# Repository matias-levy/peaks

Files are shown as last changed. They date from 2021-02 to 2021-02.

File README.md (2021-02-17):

# $peaks, a fully-functional low-cost reversion of [Mutable instrument's Peaks](https://mutable-instruments.net/modules/peaks/)

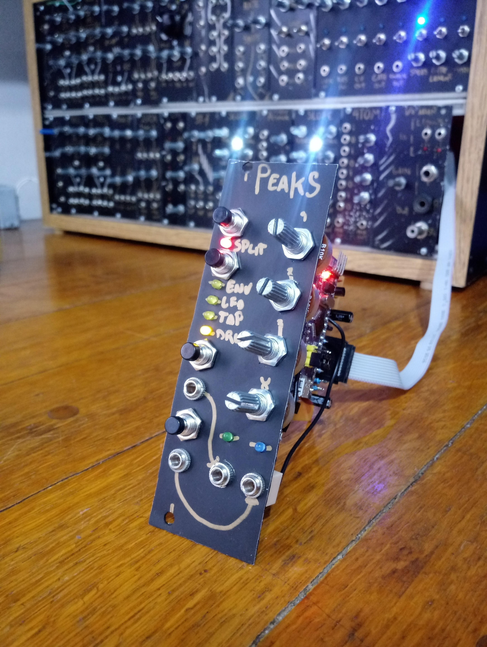
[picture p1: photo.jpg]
Photo of the finished build


## Motivation
Where I am from it is sometimes very difficult to source components for digital Eurorack modules, but I had my eyes on Peaks for a long time and I wanted to do something cheap with the same functionality. The basic premise was to use a bluepill (stm32f103c8t6 development board) and omit the DAC IC, relying on a technic called dual PWM as it is described in [openmusiclabs blog](http://www.openmusiclabs.com/learning/digital/pwm-dac/dual-pwm-circuits/index.html) and used, for example, in the popular [Mozzi Library](https://github.com/sensorium/Mozzi) for Arduino.

## Description
The project uses a single sided home-etched PCB with a couple of jumper wires, the potentiometers are regular 16mm ones mounted at the side, also helping with the mechanical stability of the build. <br>
You will need a bluepill capable of 128kb of flash, I bought mine advertised as only having 64kb, but it ended up not being the case, so it's worth the try

## Firmwares
There's the option to flash one of two firmwares that where ported. The original Mutable Instruments one is in the firmware/peaks directory. The [Mutated Mutables Dead Man's Catch](https://github.com/timchurches/Mutated-Mutables/tree/master/peaks) is in the firmware/peaks2. The later adds a lot of functionality to the module, although the UI becomes a bit confusing. <br>
Compiled binaries and HEX files are provided for both under firmware/build.

## Changes
* Added a driver for the PWM DAC running at **14 bit depth, 48Khz sampling rate.** (File in firmware/peaks/drivers/pwm_dac.h)
* Activated the clock for the TIM4 in firmware/peaks/drivers/system.cc
* **Bypassed the bootloader:** This was done as to simplify the code, it does not interfere with the calibration functionality of the module.
* Redesigned the output portion of the hardware to accommodate to the PWM levels. 

## Flashing and development
To make it easier I have left binaries and .HEX files in firmware/build, this can be flashed directly to the bluepill using [STM32CubeProgrammer](https://www.st.com/en/development-tools/stm32cubeprog.html). <br>
Another option is to install the [mutable-dev-environment](https://github.com/pichenettes/mutable-dev-environment) and replace the peaks folder with the one inside /firmware, then executing

    make -f peaks/makefile upload_serial

We use this command because the bootloader is bypassed.

## Thanks
I want to thank Emilie Gillet for open-sourcing her work which is a constant inspiration for many musicians and makers, and encourage everyone interested in this project to checkout the [Mutable instrument's Forum](https://forum.mutable-instruments.net/) in which Emilie is a very active member.

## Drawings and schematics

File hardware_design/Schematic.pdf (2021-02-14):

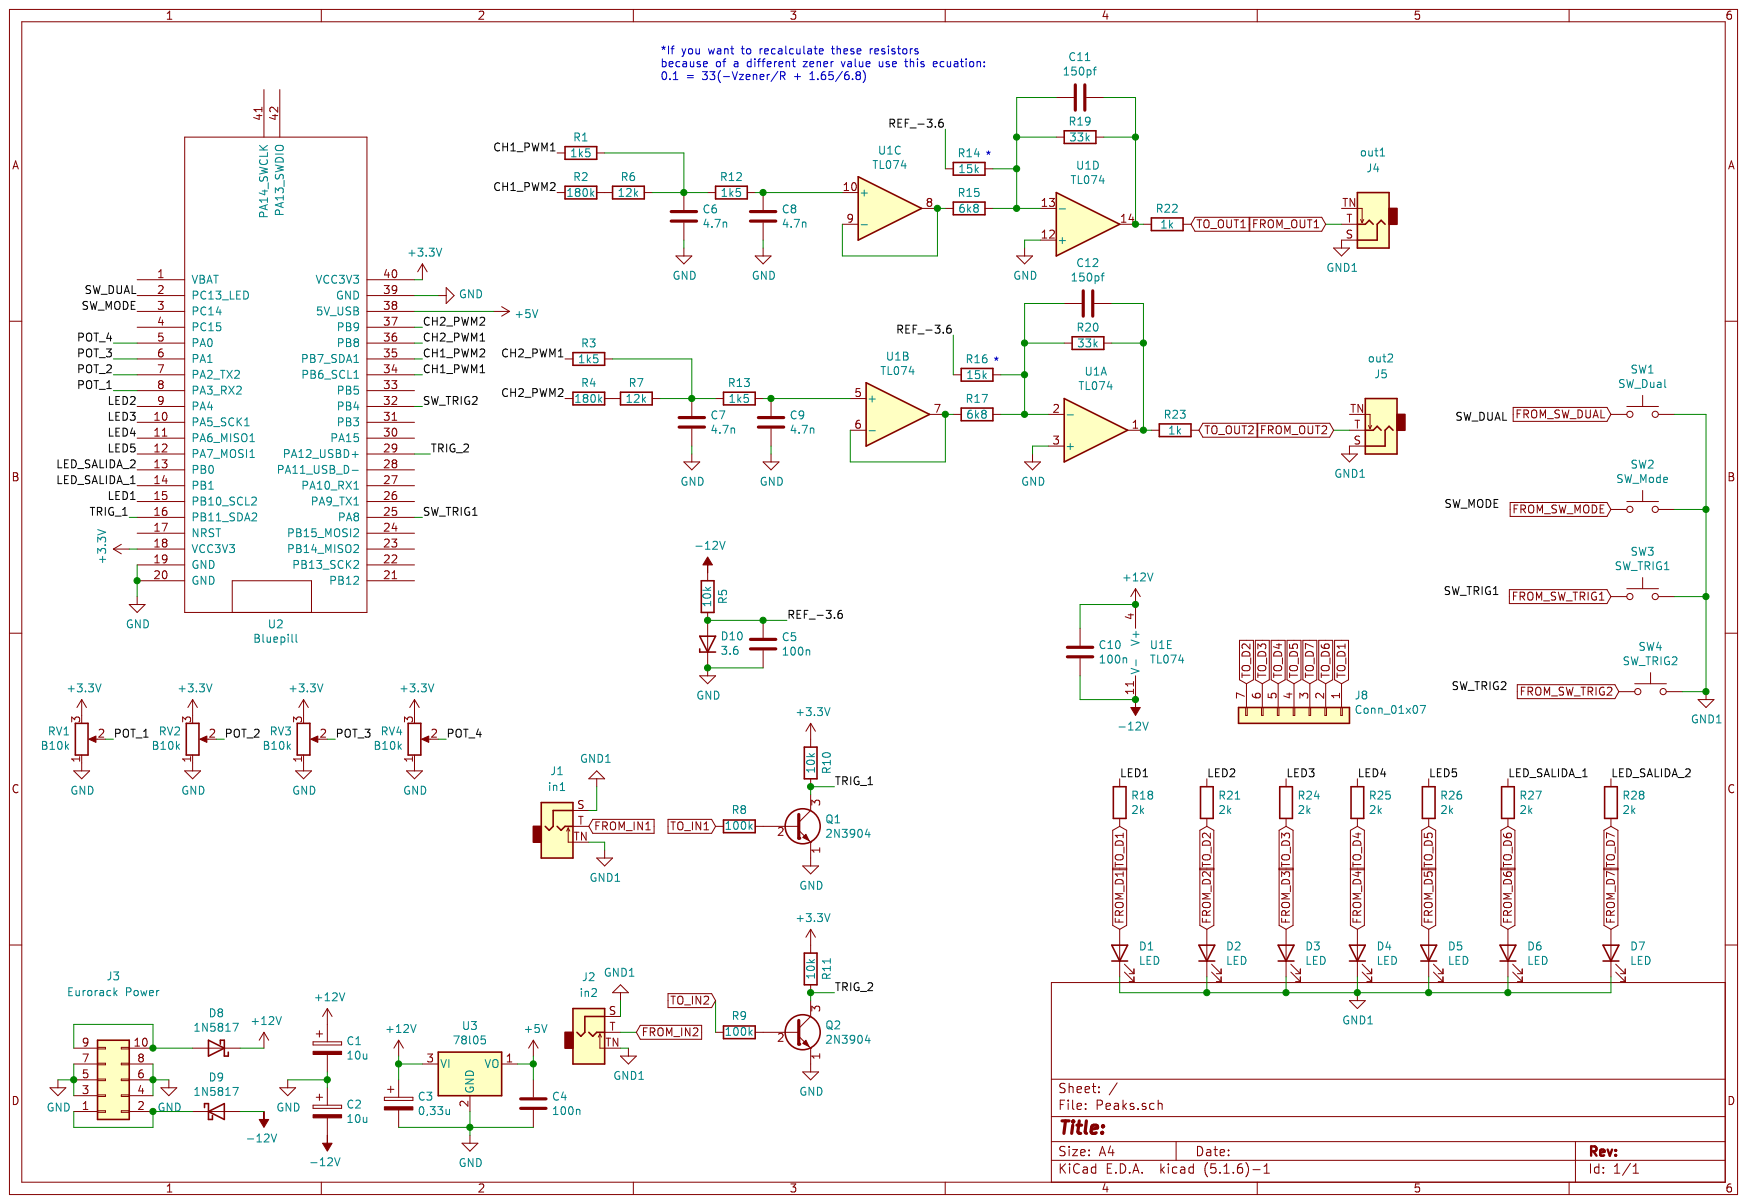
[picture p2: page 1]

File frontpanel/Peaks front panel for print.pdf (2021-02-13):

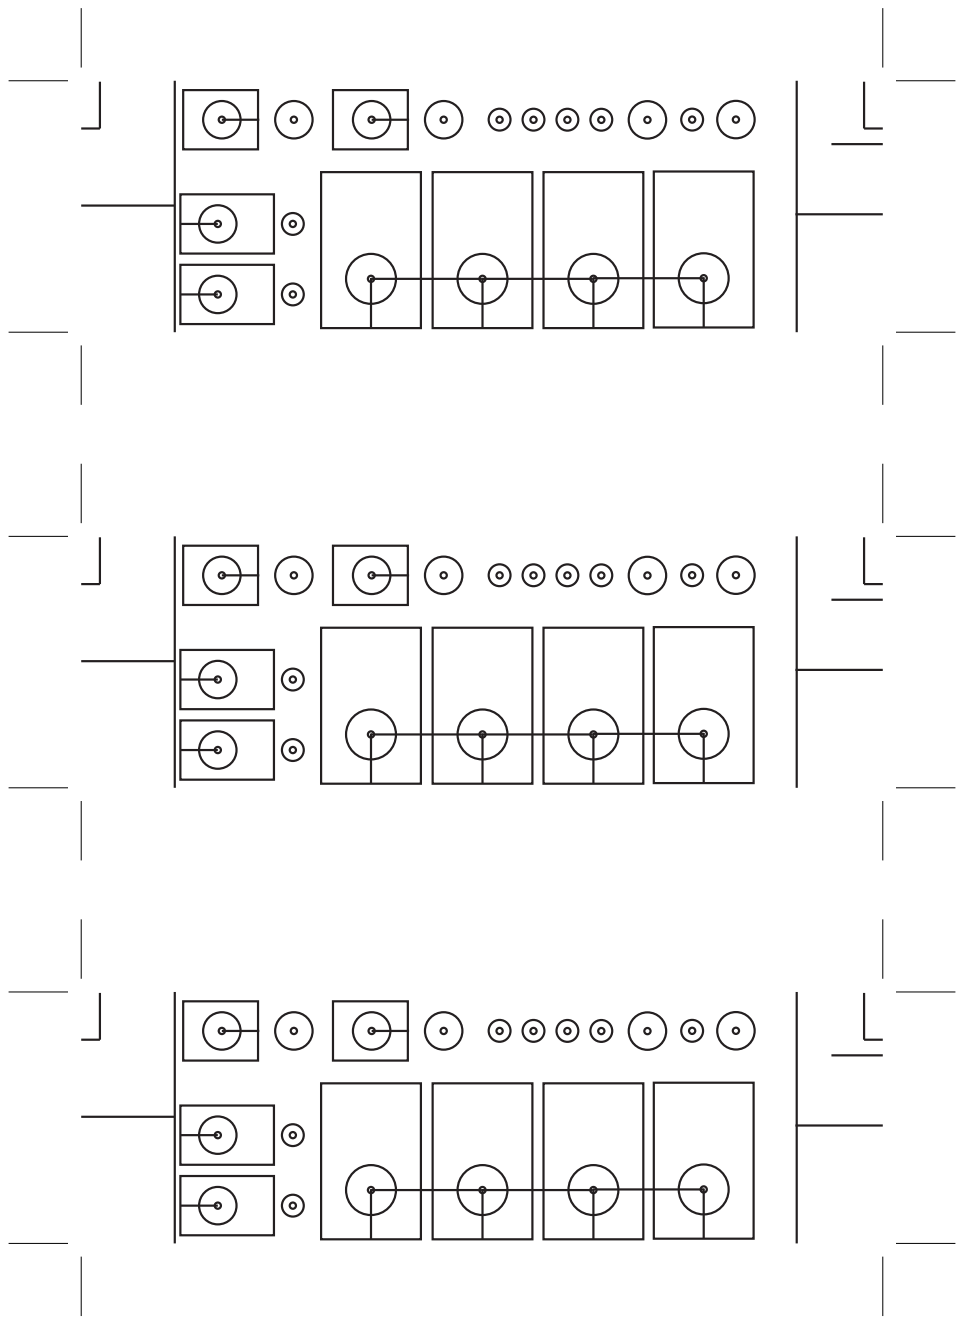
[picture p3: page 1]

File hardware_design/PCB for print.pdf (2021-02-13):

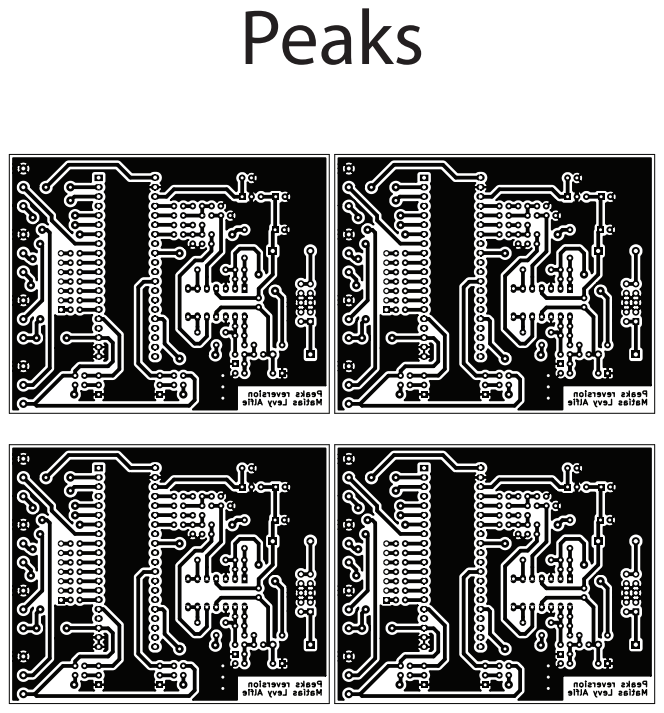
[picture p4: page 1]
Peaks

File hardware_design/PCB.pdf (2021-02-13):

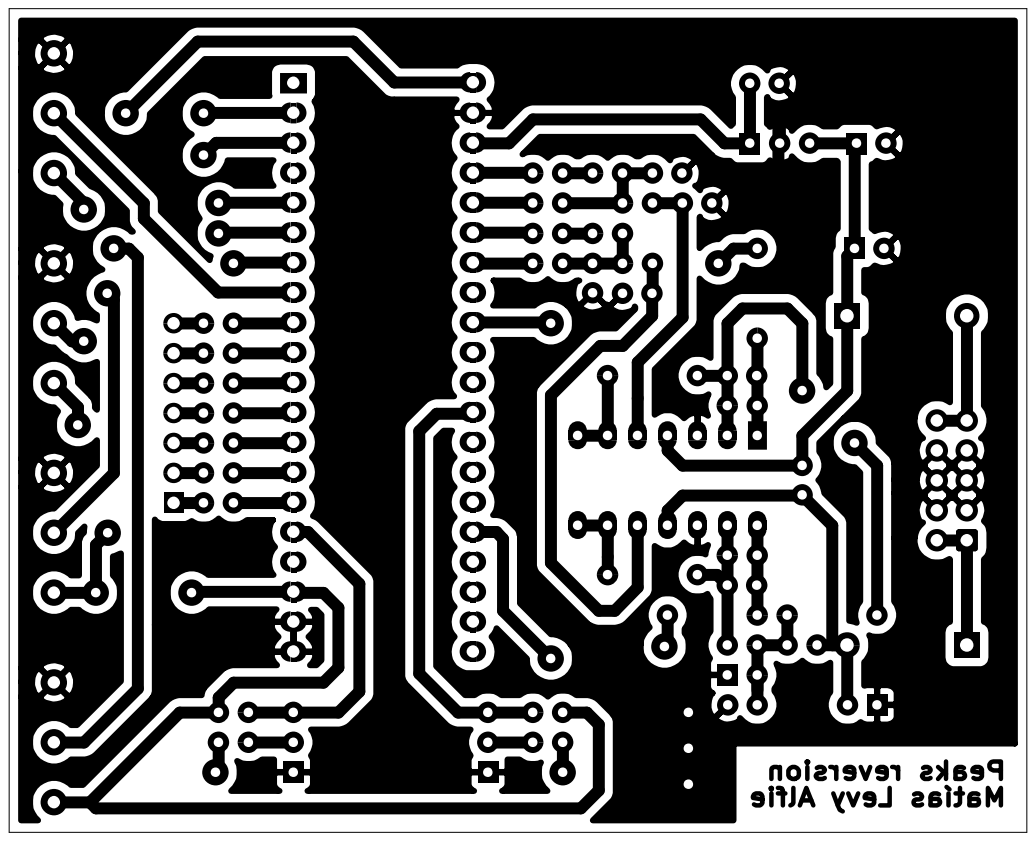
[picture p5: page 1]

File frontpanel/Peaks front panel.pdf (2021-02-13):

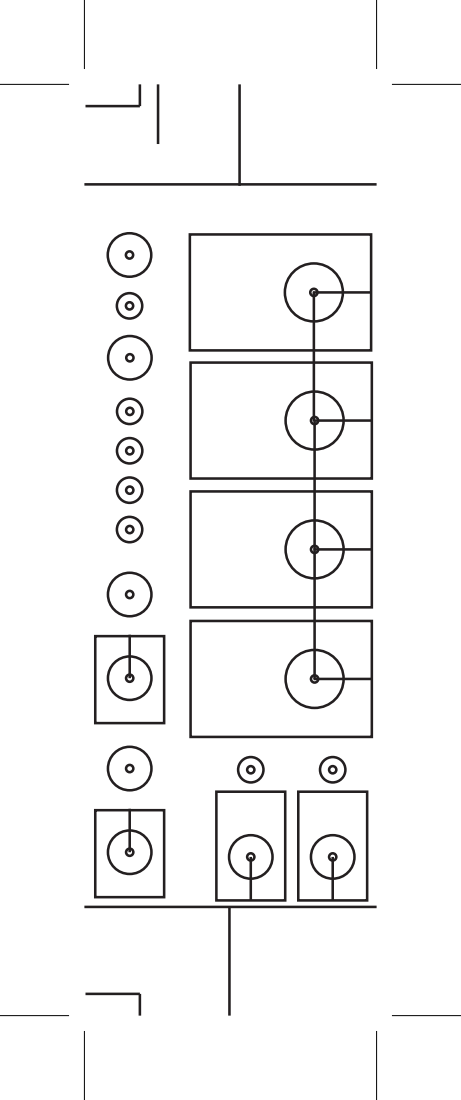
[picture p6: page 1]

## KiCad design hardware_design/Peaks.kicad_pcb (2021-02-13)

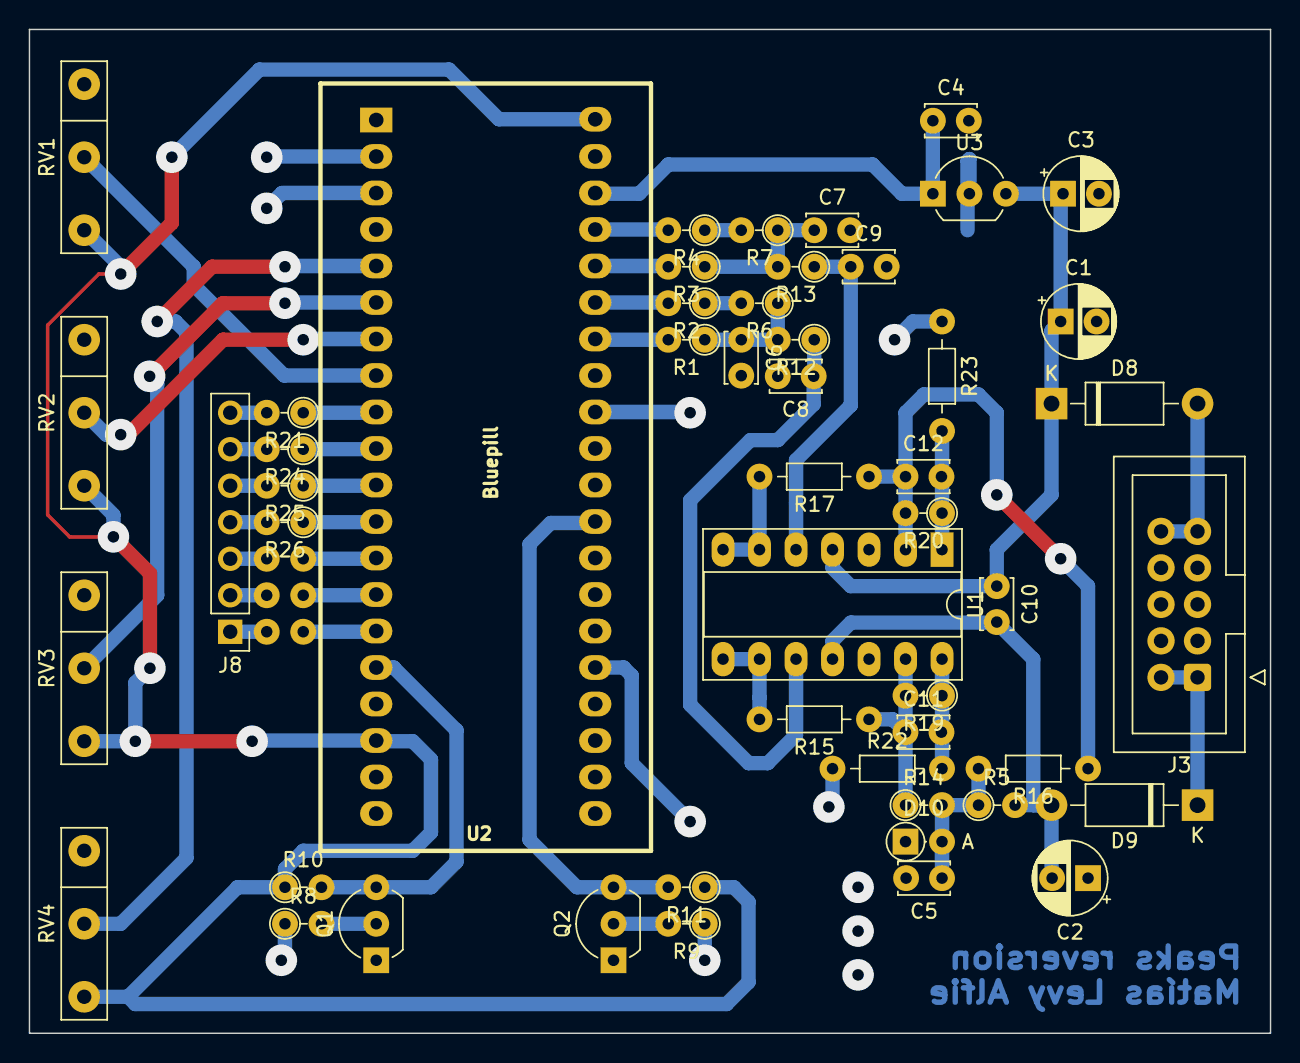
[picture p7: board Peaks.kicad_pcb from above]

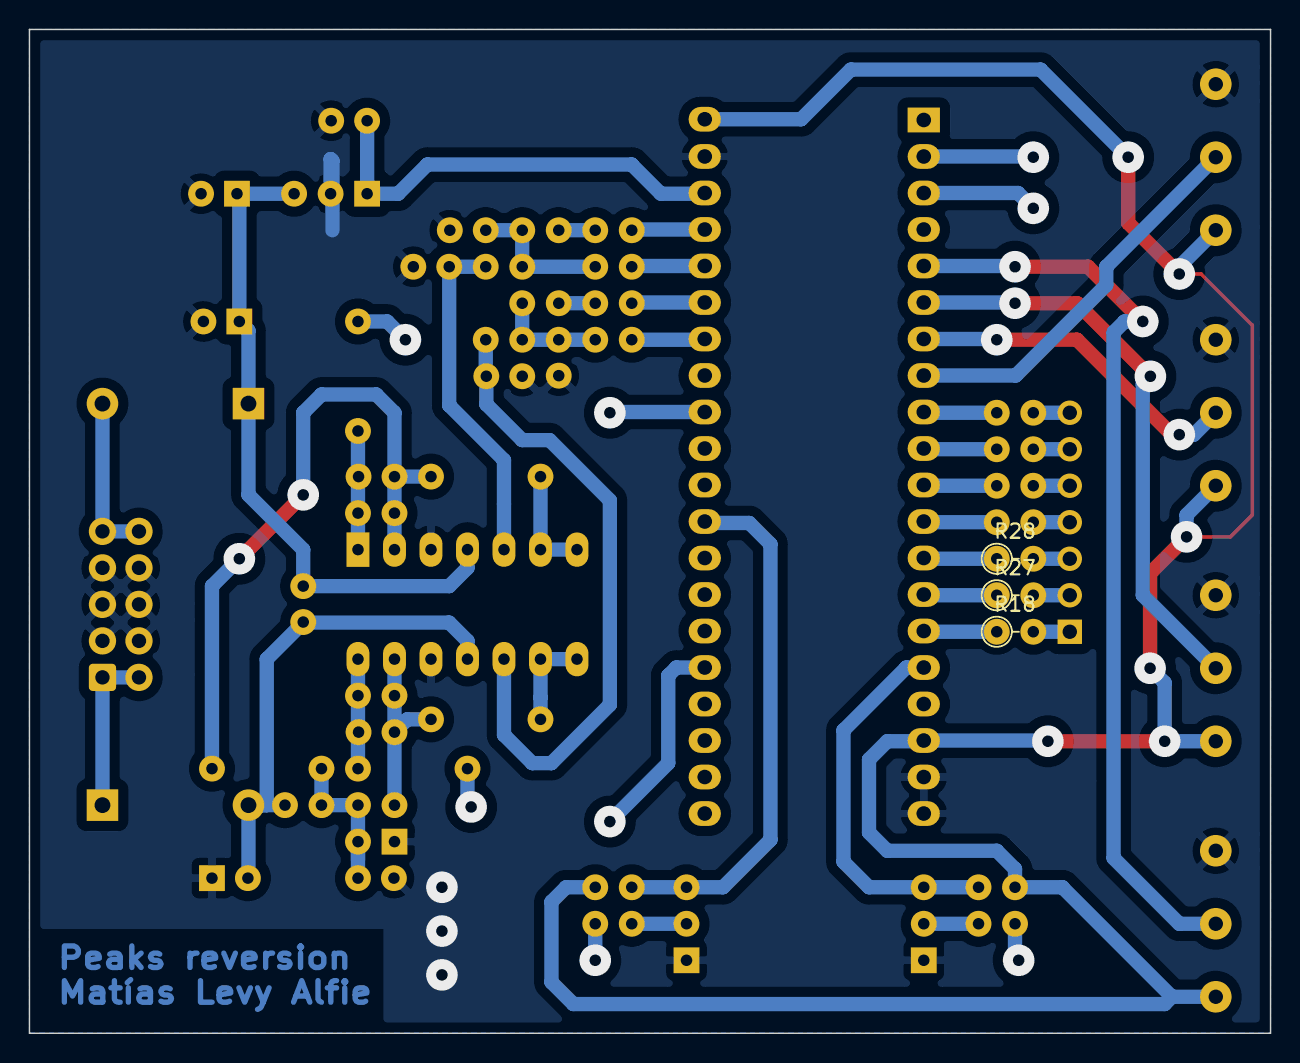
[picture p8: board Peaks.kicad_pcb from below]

Board: 2 copper layers, 86.4 x 69.8 mm, 54 parts (3 on the bottom side), 46 nets.

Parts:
C1, C2: 10u; CP_Radial_D5.0mm_P2.50mm_Large_Pads
C3: 0,33u; CP_Radial_D5.0mm_P2.50mm_Large_Pads
C4, C5, C10: 100n; C_Disc_D3.4mm_W2.1mm_P2.50mm_Large_Pads
C6, C7, C8, C9: 4.7n; C_Disc_D3.4mm_W2.1mm_P2.50mm_Large_Pads
C11, C12: 150pf; C_Disc_D3.4mm_W2.1mm_P2.50mm_Large_Pads
D8, D9: 1N5817; D_DO-41_SOD81_P10.16mm_Horizontal
D10: 3.6; D_DO-35_SOD27_P2.54mm_Vertical_AnodeUp_Large_Pads
J3: Eurorack Power; IDC-Header_2x05_P2.54mm_Vertical_Large_Pads
J8: Conn_01x07; PinHeader_1x07_P2.54mm_Vertical
Q1, Q2: 2N3904; TO-92_Inline_Wide_Large_Pads
R1, R3, R12, R13: 1k5; R_Axial_DIN0204_L3.6mm_D1.6mm_P2.54mm_Vertical_Large_Pads
R2, R4: 180k; R_Axial_DIN0204_L3.6mm_D1.6mm_P2.54mm_Vertical_Large_Pads
R5, R10, R11: 10k; R_Axial_DIN0204_L3.6mm_D1.6mm_P2.54mm_Vertical_Large_Pads
R6, R7: 12k; R_Axial_DIN0204_L3.6mm_D1.6mm_P2.54mm_Vertical_Large_Pads
R8, R9: 100k; R_Axial_DIN0204_L3.6mm_D1.6mm_P2.54mm_Vertical_Large_Pads
R14: 15k; R_Axial_DIN0204_L3.6mm_D1.6mm_P2.54mm_Vertical_Large_Pads
R15, R17: 6k8; R_Axial_DIN0204_L3.6mm_D1.6mm_P7.62mm_Horizontal_Large_Pads
R16: 15k; R_Axial_DIN0204_L3.6mm_D1.6mm_P7.62mm_Horizontal_Large_Pads
R18, R21, R24, R25, R26, R27, R28: 2k; R_Axial_DIN0204_L3.6mm_D1.6mm_P2.54mm_Vertical_Large_Pads
R19, R20: 33k; R_Axial_DIN0204_L3.6mm_D1.6mm_P2.54mm_Vertical_Large_Pads
R22, R23: 1k; R_Axial_DIN0204_L3.6mm_D1.6mm_P7.62mm_Horizontal_Large_Pads
RV1, RV2, RV3, RV4: B10k; Potenciometro
U1: TL074; DIP-14_W7.62mm_Socket_LongPads
U2: Bluepill; BluePill_STM32F103C
U3: 78l05; TO-92_Inline_Wide_Large_Pads

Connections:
+3V3: R10.1, R11.1, RV1.3, RV2.3, RV3.3, RV4.3, U2.18, U2.40
+5V: C4.1, U2.38, U3.1
+12V: C1.1, C3.1, C10.1, D8.1, U1.4, U3.3
-12V: C2.2, C10.2, D9.2, R5.2, U1.11
/CH1_PWM1: R1.2, U2.34
/CH1_PWM2: R2.2, U2.35
/CH2_PWM1: R3.2, U2.36
/CH2_PWM2: R4.2, U2.37
/LED1: R18.1, U2.15
/LED2: R21.1, U2.9
/LED3: R24.1, U2.10
/LED4: R25.1, U2.11
/LED5: R26.1, U2.12
/LED_SALIDA_1: R27.1, U2.14
/LED_SALIDA_2: R28.1, U2.13
/POT_1: RV1.2, U2.8
/POT_2: RV2.2, U2.7
/POT_3: RV3.2, U2.6
/POT_4: RV4.2, U2.5
/REF_-3.6: C5.1, D10.2, R5.1, R14.2, R16.2
/TRIG_1: Q1.3, R10.2, U2.16
/TRIG_2: Q2.3, R11.2, U2.29
GND: C1.2, C2.1, C3.2, C4.2, C5.2, C6.2, C7.2, C8.2, C9.2, D10.1, J3.3, J3.4, J3.5, J3.6, J3.7, J3.8, Q1.1, Q2.1, RV1.1, RV2.1, RV3.1, RV4.1, U1.3, U1.12, U2.19, U2.20, U2.39, U3.2
unnamed: C6.1, R1.1, R6.1, R12.2
unnamed: C7.1, R3.1, R7.1, R13.2
unnamed: C8.1, R12.1, U1.10
unnamed: C9.1, R13.1, U1.5
unnamed: C11.1, R14.1, R15.1, R19.2, U1.13
unnamed: C11.2, R19.1, R22.2, U1.14
unnamed: C12.1, R16.1, R17.1, R20.2, U1.2
unnamed: C12.2, R20.1, R23.2, U1.1
unnamed: D8.2, J3.9, J3.10
unnamed: D9.1, J3.1, J3.2
unnamed: Q1.2, R8.2
unnamed: Q2.2, R9.2
unnamed: R2.1, R6.2
unnamed: R4.1, R7.2
unnamed: R15.2, U1.8, U1.9
unnamed: R17.2, U1.6, U1.7
TO_D1: J8.1, R18.2
TO_D2: J8.7, R21.2
TO_D3: J8.6, R24.2
TO_D4: J8.5, R25.2
TO_D5: J8.4, R26.2
TO_D6: J8.2, R27.2
TO_D7: J8.3, R28.2

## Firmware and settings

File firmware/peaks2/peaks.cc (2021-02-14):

// Copyright 2014 Olivier Gillet.
//
// Author: Olivier Gillet (ol.gillet@gmail.com)
//
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
// See http://creativecommons.org/licenses/MIT/ for more information.

#include <stm32f10x_conf.h>

#include "stmlib/utils/dsp.h"
#include "stmlib/utils/ring_buffer.h"
#include "stmlib/system/system_clock.h"

#include "peaks2/drivers/pwm_dac.h"
#include "peaks2/drivers/debug_pin.h"
#include "peaks2/drivers/gate_input.h"
#include "peaks2/drivers/system.h"

#include "peaks2/calibration_data.h"
#include "peaks2/io_buffer.h"
#include "peaks2/processors.h"
#include "peaks2/ui.h"

using namespace peaks;
using namespace std;
using namespace stmlib;

Adc adc;
CalibrationData calibration_data;
PWMDac pwm_dac;
GateInput gate_input;
IOBuffer io_buffer;
Leds leds;
Switches switches;
System sys;
Ui ui;

extern "C" {

void HardFault_Handler(void) { while (1); }
void MemManage_Handler(void) { while (1); }
void BusFault_Handler(void) { while (1); }
void UsageFault_Handler(void) { while (1); }
void NMI_Handler(void) { }
void SVC_Handler(void) { }
void DebugMon_Handler(void) { }
void PendSV_Handler(void) { }

}

extern "C" {

uint16_t counter = 0;

void SysTick_Handler() {
  ui.Poll();
}

GateFlags gate_flags[2];

void TIM1_UP_IRQHandler(void) {
  // DAC refresh at 48kHz
  if (!(TIM1->SR & TIM_IT_Update)) {
    return;
  }
  TIM1->SR = (uint16_t)~TIM_IT_Update;

  bool wrote_both_channels = pwm_dac.Update();
  if (!wrote_both_channels) {
    return;
  }

  uint32_t external_gate_inputs = gate_input.Read();
  uint32_t buttons = ui.ReadPanelGateState();
  uint32_t gate_inputs = external_gate_inputs | buttons;

  IOBuffer::Slice slice = io_buffer.NextSlice(1);
  for (size_t i = 0; i < kNumChannels; ++i) {
    gate_flags[i] = ExtractGateFlags(
        gate_flags[i],
        gate_inputs & (1 << i));
    pwm_dac.Write(i, slice.block->output[i][slice.frame_index]);
  }

  // A hack to make channel 1 aware of what's going on in channel 2. Used to
  // reset the sequencer.
  slice.block->input[0][slice.frame_index] = gate_flags[0] \
      | (gate_flags[1] << 4) \
      | (buttons & 1 ? GATE_FLAG_FROM_BUTTON : 0);

  slice.block->input[1][slice.frame_index] = gate_flags[1] \
      | (buttons & 2 ? GATE_FLAG_FROM_BUTTON : 0);
}

}

int16_t output_buffer[kBlockSize];

void Process(IOBuffer::Block* block, size_t size) {
  // DebugPin::High();
  ui.PollPots();
  for (size_t i = 0; i < kNumChannels; ++i) {
    if (ui.calibrating()) {
      fill(&output_buffer[0], &output_buffer[size], 0);
    } else {
      processors[i].Process(block->input[i], output_buffer, size);
    }
    ui.set_led_brightness(i, output_buffer[0]);
    for (size_t j = 0; j < size; ++j) {
      block->output[i][j] = calibration_data.DacCode(i, output_buffer[j]);
    }
  }
  // DebugPin::Low();
}

void Init() {
  sys.Init(F_CPU / 96000 - 1, false);

  system_clock.Init();
  gate_input.Init();
  io_buffer.Init();
  pwm_dac.Init();

  calibration_data.Init();
  processors[0].Init(0);
  processors[1].Init(1);
  ui.Init(&calibration_data);

  // DebugPin::Init();

  sys.StartTimers();
}

int main(void) {
  Init();
  while (1) {
    ui.DoEvents();
    io_buffer.Process(&Process);
  }
}

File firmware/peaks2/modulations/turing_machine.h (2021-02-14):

// Copyright 2013 Olivier Gillet, 2015 Tim Churches
//
// Author: Olivier Gillet (ol.gillet@gmail.com)
// Modifications: Tim Churches (tim.churches@gmail.com)
// Modifications may be determined by examining the differences between the last commit
// by Olivier Gillet (pichenettes) and the HEAD commit at
// https://github.com/timchurches/Mutated-Mutables/tree/master/peaks
//
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
// See http://creativecommons.org/licenses/MIT/ for more information.
//
// -----------------------------------------------------------------------------
//
// Mini sequencer.

#ifndef PEAKS_MODULATIONS_TURING_MACHINE_H_
#define PEAKS_MODULATIONS_TURING_MACHINE_H_

#include "stmlib/stmlib.h"

#include <algorithm>

#include "peaks2/gate_processor.h"

#include "stmlib/utils/dsp.h"
#include "stmlib/utils/random.h"

namespace peaks {

class TuringMachine {
 public:
  TuringMachine() { }
  ~TuringMachine() { }

  void Init() {
    turing_length_ = 8;
    turing_prob_ = 0;
    turing_divider_ = 1;
    turing_span_ = 0;
    turing_shift_register_ = stmlib::Random::GetWord();
    turing_lsb_ = turing_shift_register_ & static_cast<uint32_t>(1);
    turing_remainder_lsb_ = false;
    turing_value_ = 0;
    turing_div_counter_ = 0;
  }

  inline void set_turing_length(uint16_t value) {
    if (value < 9362) {
      turing_length_ = 8;
    } else if (value < 18724) {
      turing_length_ = 12;
    } else if (value < 28086) {
      turing_length_ = 16;
    } else if (value < 37449) {
      turing_length_ = 20;
    } else if (value < 46822) {
      turing_length_ = 24;
    } else if (value < 56173) {
      turing_length_ = 28;
    } else {
      turing_length_ = 32;
    }
  }

  inline void set_turing_prob(uint16_t value) {
    if (value > 63487) {
      turing_prob_ = 65535;
    } else {
      turing_prob_ = value >> 3 ;
    }
  }

  inline void set_turing_divider(uint16_t value) {
    turing_divider_ = (value >> 13) + 1;
  }

  inline void set_turing_span(uint16_t value) {
    turing_span_ = value;
  }

  void Configure(uint16_t* parameter, ControlMode control_mode) {
    if (control_mode == CONTROL_MODE_HALF) {
      set_turing_prob(parameter[0]);
      set_turing_span(parameter[1]);
    } else {
      set_turing_prob(parameter[0]);
      set_turing_span(parameter[1]);
      set_turing_length(parameter[2]);
      set_turing_divider(parameter[3]);
    }
  }

  void Process(const GateFlags* gate_flags, int16_t* out, size_t size) {
    while (size--) {
      GateFlags gate_flag = *gate_flags++;

      if (gate_flag & GATE_FLAG_RISING) {
        ++turing_div_counter_;
        if (turing_div_counter_ >= turing_divider_) {
          turing_div_counter_ = 0 ;
          // read the LSB
          turing_lsb_ = turing_shift_register_ & static_cast<uint32_t>(1);
          // read the LSB in the remainder of the shift register
          if (turing_length_ < 32) {
             turing_remainder_lsb_ = turing_shift_register_ & (static_cast<uint32_t>(1) << turing_length_);
          }
          // rotate the shift register
          turing_shift_register_ = turing_shift_register_ >> 1;
          // add back the LSB into the MSB postion
          if (turing_lsb_) {
             turing_shift_register_ |= (static_cast<uint32_t>(1) << (turing_length_ - 1));
          } else {
             turing_shift_register_ &= (~(static_cast<uint32_t>(1) << (turing_length_ - 1)));
          }
          // add back the LSB to the remainder of the shift register
          if (turing_length_ < 32) {
             if (turing_remainder_lsb_) {
                turing_shift_register_ |= (static_cast<uint32_t>(1) << 31);
             } else {
                turing_shift_register_ &= (~(static_cast<uint32_t>(1) << 31));
             }
          }
          // Decide whether to re-initialise and skip the rest, or not
          if (false) {
              turing_shift_register_ = stmlib::Random::GetWord();
              turing_lsb_ = turing_shift_register_ & static_cast<uint32_t>(1);
          } else {
  			// read the LSB
  			turing_lsb_ = turing_shift_register_ & static_cast<uint32_t>(1);
  			// read the LSB in the remainder of the shift register
  			if (turing_length_ < 32) {
  			   turing_remainder_lsb_ = turing_shift_register_ & (static_cast<uint32_t>(1) << turing_length_);
  			}
  			// rotate the shift register
  			turing_shift_register_ = turing_shift_register_ >> 1;
  			// add back the LSB into the MSB postion
  			if (turing_lsb_) {
  			   turing_shift_register_ |= (static_cast<uint32_t>(1) << (turing_length_ - 1));
  			} else {
  			   turing_shift_register_ &= (~(static_cast<uint32_t>(1) << (turing_length_ - 1)));
  			}
  			// add back the LSB to the remainder of the shift register
  			if (turing_length_ < 32) {
  			   if (turing_remainder_lsb_) {
  				  turing_shift_register_ |= (static_cast<uint32_t>(1) << 31);
  			   } else {
  				  turing_shift_register_ &= (~(static_cast<uint32_t>(1) << 31));
  			   }
  			}
  			// decide whether to flip the LSB
  			uint16_t random = stmlib::Random::GetSample();
  			if (random < turing_prob_) {
  			   // bit-flip the LSB
  			   turing_shift_register_ = turing_shift_register_ ^ static_cast<uint32_t>(1) ;
  	        }
  	    }
          turing_byte_ = turing_shift_register_ & static_cast<uint32_t>(0xFF);
          turing_value_ = (turing_byte_ * (turing_span_ >> 10)); // was 9
        }
      }
      *out++ = turing_value_;
    }
  }

 private:
  uint16_t turing_length_;
  uint16_t turing_prob_;
  uint16_t turing_divider_;
  uint16_t turing_span_;
  uint32_t turing_shift_register_;
  bool turing_lsb_;
  bool turing_remainder_lsb_;
  uint32_t turing_byte_;
  int16_t turing_value_;
  uint8_t turing_div_counter_;

  DISALLOW_COPY_AND_ASSIGN(TuringMachine);
};

}  // namespace peaks

#endif  // PEAKS_MODULATIONS_TURING_MACHINE_H_

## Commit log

2021-02-14 Added Personal footprint library in hardware_design
2021-02-14 Added Schematic.pdf
